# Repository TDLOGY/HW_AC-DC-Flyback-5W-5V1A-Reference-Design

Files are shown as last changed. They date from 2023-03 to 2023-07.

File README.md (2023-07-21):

# AC-DC-Flyback-5W-5V1A-Reference-Design
AC DC Flyback 5W 5V1A Reference Design
---

- __[Linh Kiện Thủ Đức](https://linhkienthuduc.com/)__ - Electronics shop in Viet Nam

You will like those projects!
## Please note that this project just for learning basic of AC-DC power supply purpose, will not care about safety standard. Only use it for application which need basic safety!!!
---

### Reference Design for flyback AC-DC circuit with 5W power output 5V & 1A 8-)
#### Details about the design procedure you can find here - __[Design guideline (Vietnamese)](https://linhkienthuduc.com/chia-se-thiet-ke-mau-va-tinh-toan-thiet-ke-mach-nguon-xung-flyback-ac-dc-5w-5v-1a-cho-cac-ung-dung-cong-suat-thap)__

Download Schematic PDF with detail footprint, value, part number **( you should download it and use Foxit Reader to click on the component to see it)**
__[Download here](https://github.com/TDLOGY/AC-DC-Flyback-5W-5V1A-Reference-Design/blob/main/5V2A_PS_EE1310_Schematic.pdf)__

Note 1: **Reference value of resistor can be adjust base on the design to have exactly value**

Note 2: **The transformer used in design is not used for higher voltage output ex 9V,12v,15V...**

#### Picture reference

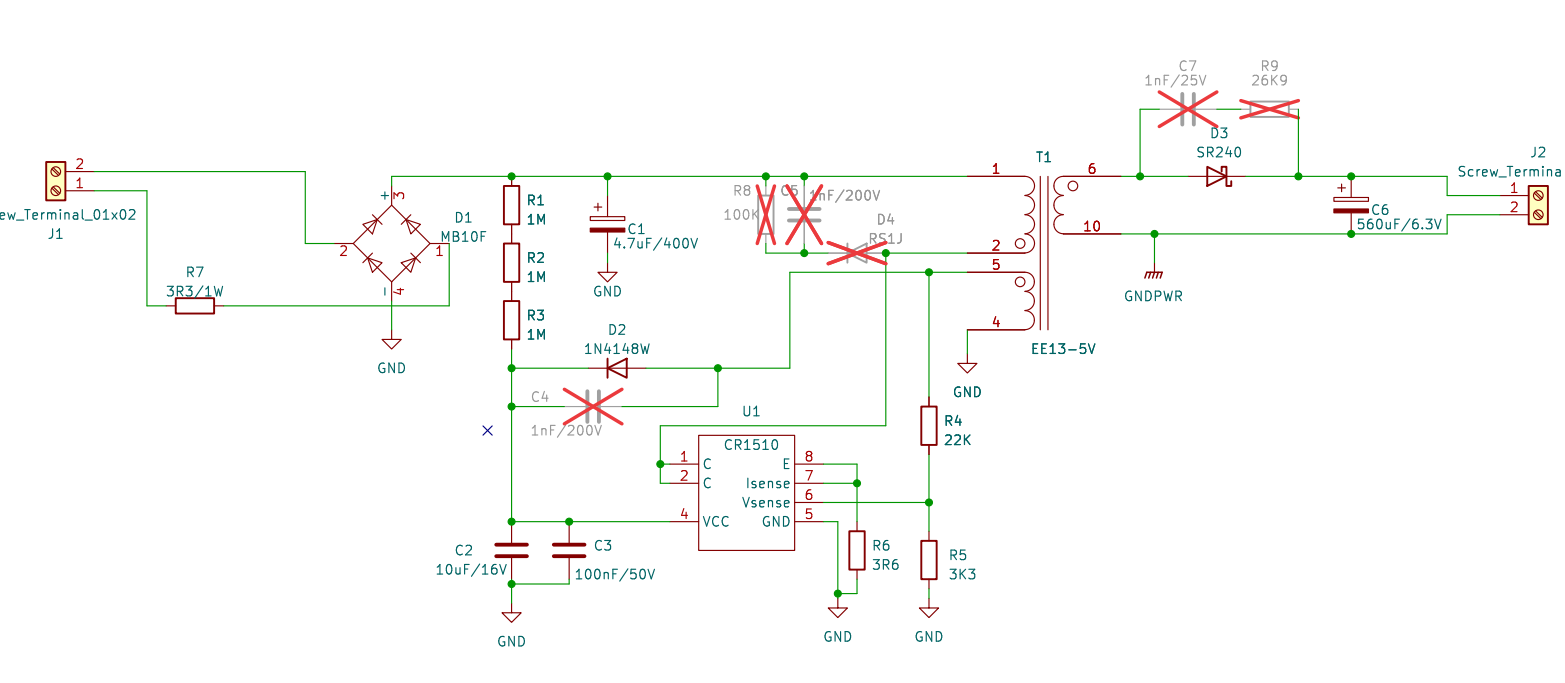
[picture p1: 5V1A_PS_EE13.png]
Schematic


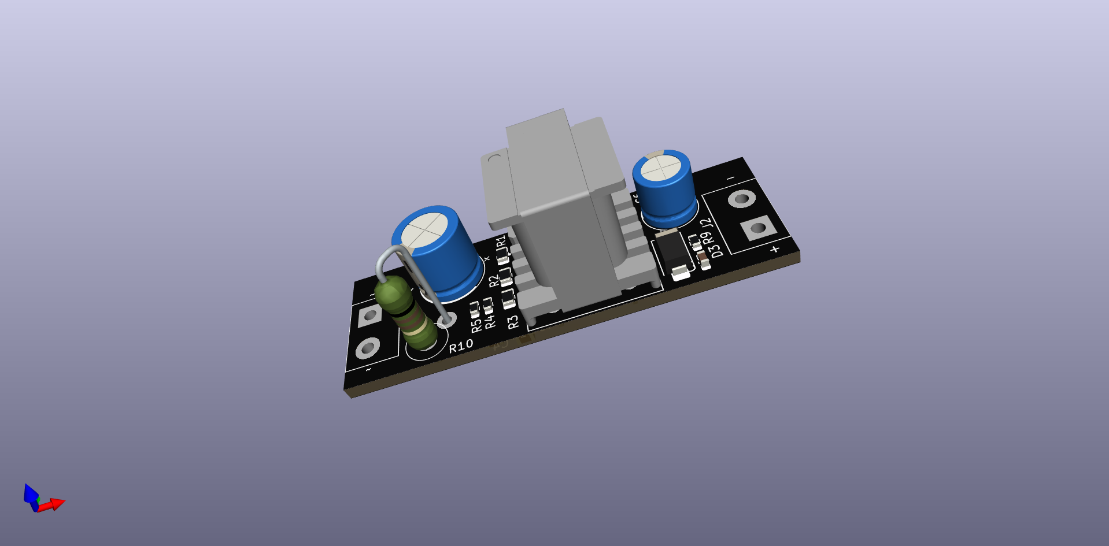
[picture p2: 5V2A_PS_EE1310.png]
3D1


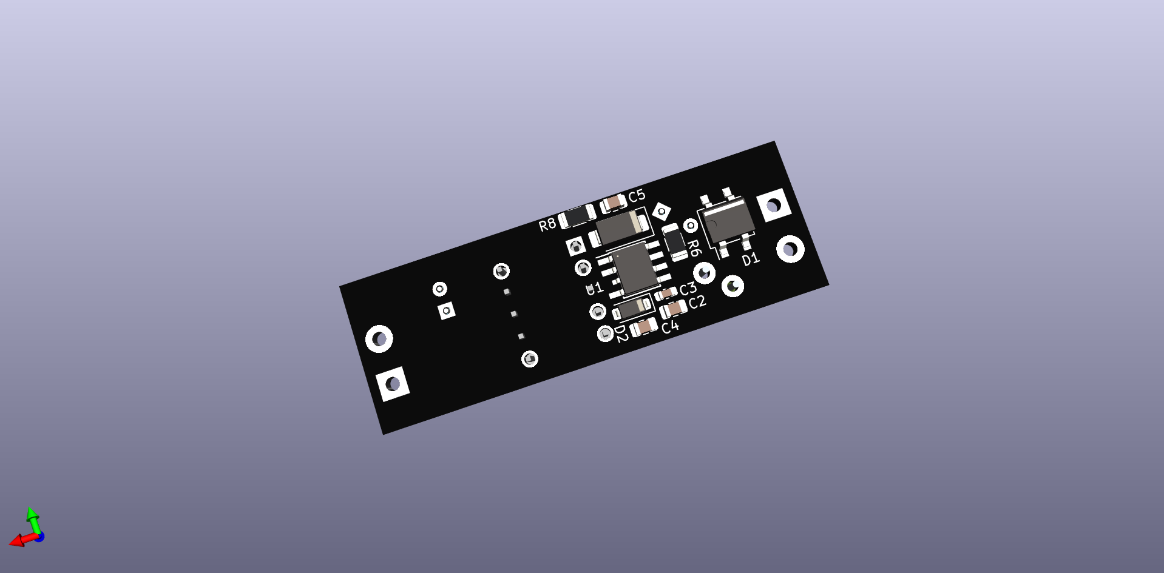
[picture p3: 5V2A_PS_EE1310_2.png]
3D2


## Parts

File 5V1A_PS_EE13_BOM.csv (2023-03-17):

Reference | Value | Footprint | LINK Mua | LKTD PN | Qty
T1 | EE13-5V | 0_Custom:BOBBIN_EE13_4_2 | https://linhkienthuduc.com/bien-ap-xung-ee13-5v-1a-5w | TD0683 | 1
U1 | CR1510 | Package_SO:SOIC-8-N3_3.9x4.9mm_P1.27mm | https://linhkienthuduc.com/cr1510-ic-dieu-khien-nguon-flyback-5w | TD0594 | 1
D3 | SR240 | Diode_SMD:D_SMA | https://linhkienthuduc.com/sr240-ss24-sma-diode-schottky-2a-40v-do-214ac | TD0593 | 1
C3 | 100nF/50V | Capacitor_SMD:C_0603_1608Metric | https://linhkienthuduc.com/tu-dien-ceramic-100nf-50v-0603 | TD0582 | 1
C2 | 10uF/16V | Capacitor_SMD:C_0805_2012Metric | https://linhkienthuduc.com/tu-dien-ceramic-10uf-16v-0805 | TD0581 | 1
R1-R3 | 1M | Resistor_SMD:R_0603_1608Metric | https://linhkienthuduc.com/dien-tro-1m-ohm-0603-5 | TD0578 | 3
J1, J2 | Screw_Terminal_01x02 | TerminalBlock:TerminalBlock_bornier-2_P5.08mm | https://linhkienthuduc.com/kf301-2-v-domino-2-chan-thang-5-08mm-han-pcb-xanh-duong | TD0478 | 2
C1 | 4.7uF/400V | Capacitor_THT:CP_Radial_D8.0mm_P3.50mm | https://linhkienthuduc.com/tu-hoa-4-7uf-400v-8x13mm | TD0464 | 1
D2 | 1N4148W | Diode_SMD:D_SOD-123 | https://linhkienthuduc.com/diode-1n4148w-75v-150ma | TD0196 | 1
R6 | 3R6 | Resistor_SMD:R_1206_3216Metric | https://linhkienthuduc.com/dien-tro-3-6-ohm-0805-1 | TD0188 | 1
R7 | 3R3/2W | 0_Custom:R_Radial_Power_1W-12x4.5 | https://linhkienthuduc.com/dien-tro-3-3-ohm-1w-5 | TD0100 | 1
D1 | MB10F | Package_TO_SOT_SMD:TO-269AA | https://linhkienthuduc.com/mb10f-cau-chinh-luu-1kv-0-5a-sop-4 | SP000212 | 1
R5 | 3K3 | Resistor_SMD:R_0603_1608Metric | https://linhkienthuduc.com/dien-tro-3-3-kohm-0603-5 | SP000187 | 1
C6 | 560uF/6.3V | Capacitor_THT:CP_Radial_D6.3mm_P2.50mm | https://linhkienthuduc.com/tu-nhom-cam-xuyen-lo-560uf-6-3v-6x8-low-esr | SP000110 | 1
R8 | 100K | Resistor_SMD:R_1206_3216Metric | https://www.thegioiic.com/dien-tro-100-kohm-1206-5 |  | 1
R4, R9 | 26K9 | Resistor_SMD:R_0603_1608Metric | https://www.thegioiic.com/dien-tro-24-kohm-0603-5 |  | 2
D4 | RS1J | Diode_SMD:D_SMA | https://linhkienthuduc.com/rs1m-sma-fast-diode-1a-1000v |  | 1
C7 | 1nF/25V | Capacitor_SMD:C_0603_1608Metric |  |  | 1
C4, C5 | 1nF/200V | Capacitor_SMD:C_0805_2012Metric |  |  | 2

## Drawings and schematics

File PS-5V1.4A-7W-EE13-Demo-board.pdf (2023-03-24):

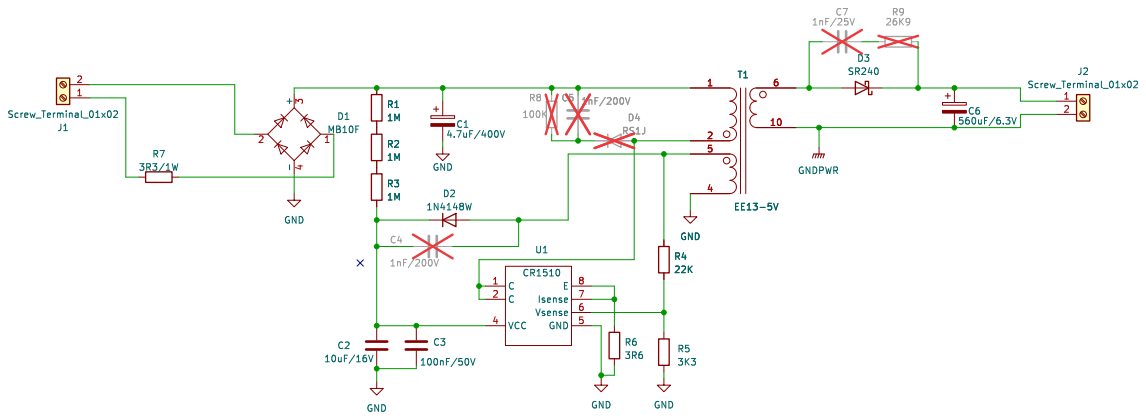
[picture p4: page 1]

TDMAKER.SPACE | | | | Flyback | 5V 1A | basic

2020-03-18 | A4 | 1/1 WWW.TDLOGY.COM

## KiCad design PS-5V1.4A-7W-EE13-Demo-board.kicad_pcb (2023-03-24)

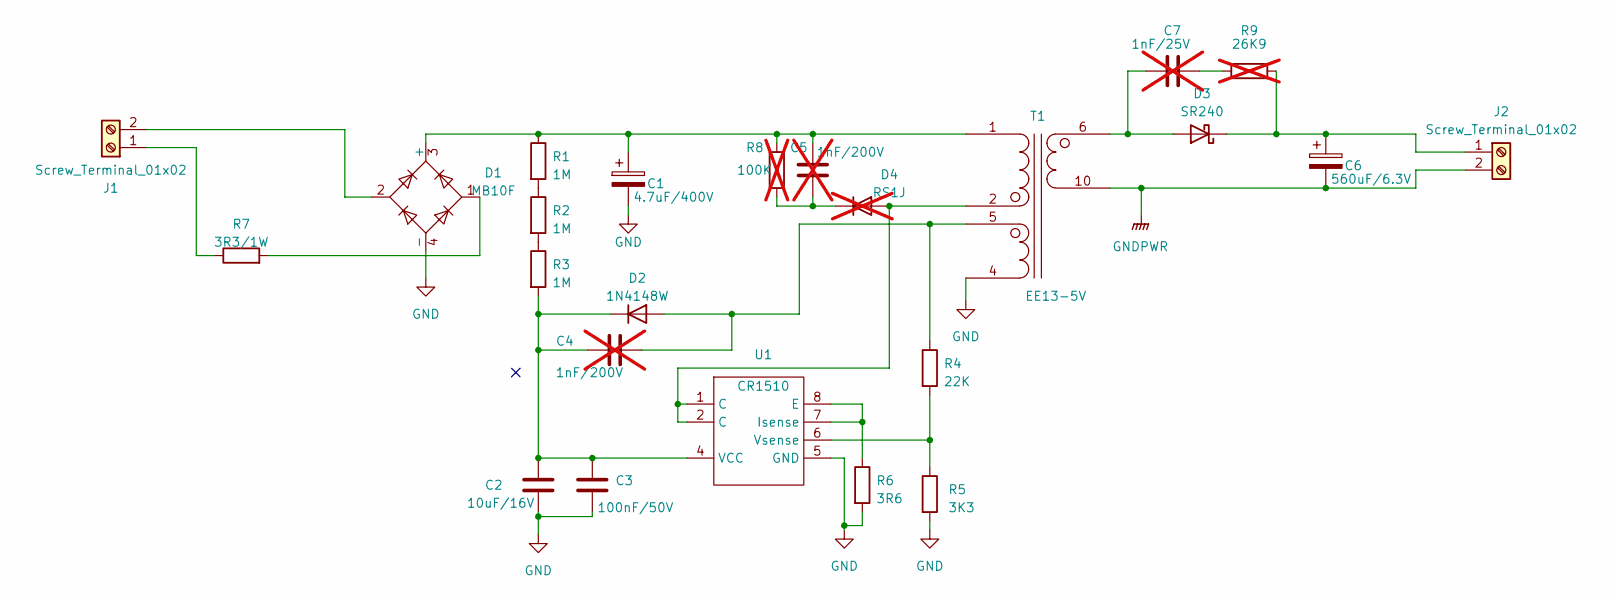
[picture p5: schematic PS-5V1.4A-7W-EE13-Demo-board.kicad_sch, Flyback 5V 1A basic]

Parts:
C1: 4.7uF/400V; CP_Radial_D8.0mm_P3.50mm
C2: 10uF/16V; C_0805_2012Metric
C3: 100nF/50V; C_0603_1608Metric
C4, C5: 1nF/200V; C_0805_2012Metric; not fitted
C6: 560uF/6.3V; CP_Radial_D6.3mm_P2.50mm
C7: 1nF/25V; C_0603_1608Metric; not fitted
D1: MB10F; TO-269AA
D2: 1N4148W; D_SOD-123
D3: SR240; D_SMA
D4: RS1J; D_SMA; not fitted
J1, J2: Screw_Terminal_01x02; TerminalBlock_bornier-2_P5.08mm
R1, R2, R3: 1M; R_0603_1608Metric
R4: 22K; R_0603_1608Metric
R5: 3K3; R_0603_1608Metric
R6: 3R6; R_1206_3216Metric
R7: 3R3/1W; R_Radial_Power_1W-12x4.5
R8: 100K; R_1206_3216Metric; not fitted
R9: 26K9; R_0603_1608Metric; not fitted
T1: EE13-5V; BOBBIN_EE13_4_2
U1: CR1510; SOIC-8-N3_3.9x4.9mm_P1.27mm

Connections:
GND: C1.2, C2.2, C3.2, D1.4 (-), R5.2, R6.2, T1.4 (GND), U1.5 (GND)
GNDPWR: C6.2, J2.2, T1.10
unnamed: C7.2, R9.1
unnamed: C1.1, C5.2, D1.3 (+), R1.1, R8.1, T1.1
unnamed: D1.1, R7.2
unnamed: C4.2, D2.2 (A), R4.1, T1.5 (Aux)
unnamed: C2.1, C3.1, C4.1, D2.1 (K), R3.2, U1.4 (VCC)
unnamed: C7.1, D3.2 (A), T1.6
unnamed: C6.1, D3.1 (K), J2.1, R9.2
unnamed: D4.2 (A), T1.2 (AB), U1.1 (C), U1.2 (C)
unnamed: C5.1, D4.1 (K), R8.2
unnamed: J1.1, R7.1
unnamed: D1.2, J1.2
unnamed: R1.2, R2.1
unnamed: R2.2, R3.1
unnamed: R6.1, U1.7 (Isense), U1.8 (E)
unnamed: R4.2, R5.1, U1.6 (Vsense)

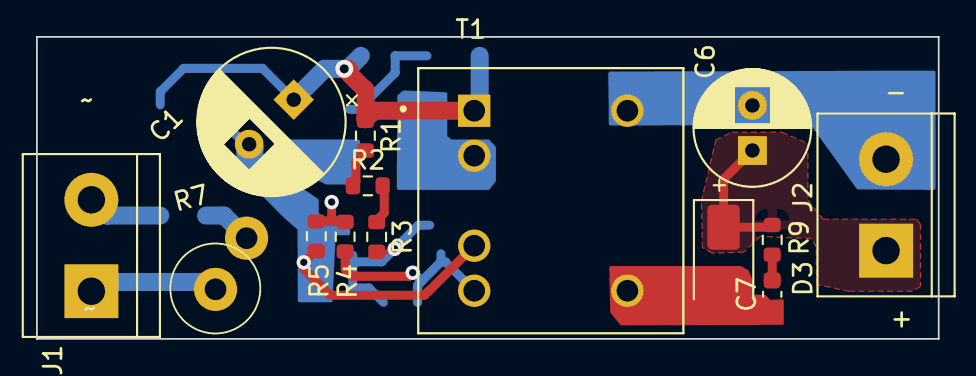
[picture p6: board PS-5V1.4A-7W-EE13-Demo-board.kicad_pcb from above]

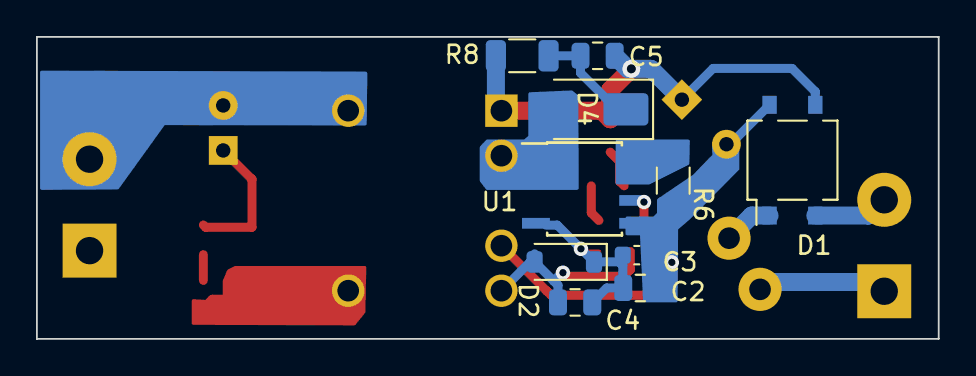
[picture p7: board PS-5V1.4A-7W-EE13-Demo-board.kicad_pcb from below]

Board: 2 copper layers, 50.1 x 16.8 mm, 24 parts (10 on the bottom side), 17 nets.

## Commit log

2023-03-17 Update Schematic
2023-03-17 Transformer Library Kicad and 3d step model
2023-03-17 Picture schematic
2023-03-17 Bill of material
    [5V1A_PS_EE13_BOM.csv]
2023-03-19 Schematic PDF
2023-03-19 Schematic picture
2023-03-19 Schematic pciture
2023-03-19 Source file design in kicad
    [PS-5V1.4A-7W-EE13-Demo-board.kicad_pcb, PS-5V1.4A-7W-EE13-Demo-board.kicad_sch]
2023-03-24 Update schematic and footprint
    [PS-5V1.4A-7W-EE13-Demo-board.kicad_pcb, PS-5V1.4A-7W-EE13-Demo-board.kicad_sch]
